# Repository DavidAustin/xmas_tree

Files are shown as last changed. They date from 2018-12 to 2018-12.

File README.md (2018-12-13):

# xmas_tree

An introduction-to-electronics project for kids around 10.

## Assembly

Assemble according to the schematic.

Soldering should be easy - except for the USB connector and perhaps the micro.

For the USB connector:
1. Put the connector in place, and hold it while flipping the PCB over.
2. Solder one of the ground pins that comes through the PCB to hold in place
3. Double check that it's in the right spot
4. Solder the remaining ground pins from the bottom.
5. Solder the signal pins using as little solder as you can.
6. If you bridge two pins, then you can use solder wick or remove with the soldering iron

To remove solder with the soldering iron, clean the tip with a wet sponge, apply the tip to the excess solder
and it will pick up a small amount.  Repeat cleaning and appplying tip to excess solder many times - say 10.

For the micro:
1. Ensure the right way around - there's a dot marking pin 1 - should go near the "U1" label.
2. Put in place and solder just one pin to hold it
3. Ensure in place, melt the soldered pin to adjust as necessary
4. Solder another pin on the far side
5. Ensure placement is still good.
6. Solder remaining pins
7. If you bridge two pins, then you can use solder wick or remove with the soldering iron

To remove solder with the soldering iron, clean the tip with a wet sponge, apply the tip to the excess solder
and it will pick up a small amount.  Repeat cleaning and appplying tip to excess solder many times - say 10.

For all the surface mount parts:
1. Apply solder to one pad
2. Position the part and melt the solder to join the part
3. Solder the remaining pad

For the LEDs (colour and front/back is at the user's discretion):
1. Short legs go near the flat side of the circle on the PCB outline - they all face the same direction
2. Put one leg in each hole and push down fairly close to the PCB.
3. Spread the legs slightly to hold in place
4. Solder both legs
5. Cut off excess with wire cutters

## Compiling

Under linux, avr-gcc is required.  Compile by typing

make

## Programming

sudo dfu-programmer atmega16u2 erase

sudo dfu-programmer atmega16u2 flash main.hex 

sudo dfu-programmer atmega16u2 start

To re-enter bootloader programming over USB, short (connect) between R21 and the nearby battery holder
and press the reset button.  A paperclip can be used.  When done right, LED21 will be on during the reset.

## Known Issues

Running from batteries will require programming the fuses - which can't be done over USB.  To be completed...

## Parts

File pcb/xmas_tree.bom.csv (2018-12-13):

Description | Device | Value | Footprint | Quantity | Supplier | Order Code | References
BATTERY HOLDER COIN 20MM SMD | BU2032SM-BT-GTR |  | CR2032_HOLDER | 2 | Digikey | BU2032SM-BT-GCT-ND | B1;B2
SWITCH TACTILE SPST-NO 0.05A 12V | SWITCH_PUSHBUTTON_NO |  | TACT6mm | 1 | Digikey | CKN9112CT-ND | BUT1
CAP CER 0.1UF 50V Y5V 0805 | CAPACITOR | 100nF | my0805 | 2 | Digikey | 1276-1007-1-ND | C1;C6
CAP CER 22PF 25V C0G/NP0 0805 | CAPACITOR | 22pF | my0805 | 2 | Digikey | 732-7829-1-ND | C2;C3
CAP CER 1UF 25V X7R 0805 | CAPACITOR | 1uF | my0805 | 1 | Digikey | 1276-1066-1-ND | C4
CONN RCPT USB2.0 MICRO B SMD R/A | 10118194-0001LF |  | usb_micro_b_10118194 | 1 | Digikey | 609-4618-1-ND | CONN1
LED RED CLEAR 5MM OVAL T/H | C5SMF-RJF-CT0W0BB2 |  | LED_5 | 7 | Digikey | C5SMF-RJF-CT0W0BB2CT-ND | LED10;LED11;LED12;LED13;LED14;LED8;LED9
LED GREEN CLEAR T-1 3/4 T/H | HLMP3950A |  | LED_5 | 7 | Digikey | 1080-1059-ND | LED15;LED16;LED17;LED18;LED19;LED20;LED21
5MM WHITE LED W/ WIDE VIEWING AN | BL-BZX3V4V-1-B02 |  | LED_5 | 7 | Digikey | BL-BZX3V4V-1-B02-ND | LED1;LED2;LED3;LED4;LED5;LED6;LED7
RES 120 OHM 5% 1/8W 0805 | RESISTOR | 120R | my0805 | 21 | Digikey | RMCF0805JT120RCT-ND | R1;R10;R11;R12;R13;R14;R15;R16;R17;R18;R19;R2;R20;R21;R3;R4;R5;R6;R7;R8;R9
CRGCQ 0805 22R 5% | RESISTOR | 22R | my0805 | 2 | Digikey | A130124CT-ND | R22;R23
RES 10K OHM 5% 1/8W 0805 | RESISTOR | 10k | my0805 | 1 | Digikey | RMCF0805JT10K0DKR-ND | R24
IC MCU 8BIT 16KB FLASH 32TQFP | ATMEGA16U2-AU |  | QFP32_70x70 | 1 | Digikey | ATMEGA16U2-AU-ND | U1
CRYSTAL 16.0000MHZ 18PF SMD | ABLS-16.000MHZ-B4-T |  | XTAL2_150x50 | 1 | Digikey | 535-10226-1-ND | X1
DNF PARTS:
Virtual part | HOLE |  | hole5 | 0 |  |  | H1
Virtual part | terminal |  | pad50x20 | 0 |  |  | T1
Virtual part | terminal |  | pad50x20 | 0 |  |  | T2
Virtual part | terminal |  | pad50x20 | 0 |  |  | T3
Virtual part | terminal |  | pad50x20 | 0 |  |  | T4
Virtual part | terminal |  | pad50x20 | 0 |  |  | T5
Virtual part | terminal |  | pad50x20 | 0 |  |  | T6
Virtual part | terminal |  | pad50x20 | 0 |  |  | T7
Virtual part | terminal |  | pad50x20 | 0 |  |  | T8

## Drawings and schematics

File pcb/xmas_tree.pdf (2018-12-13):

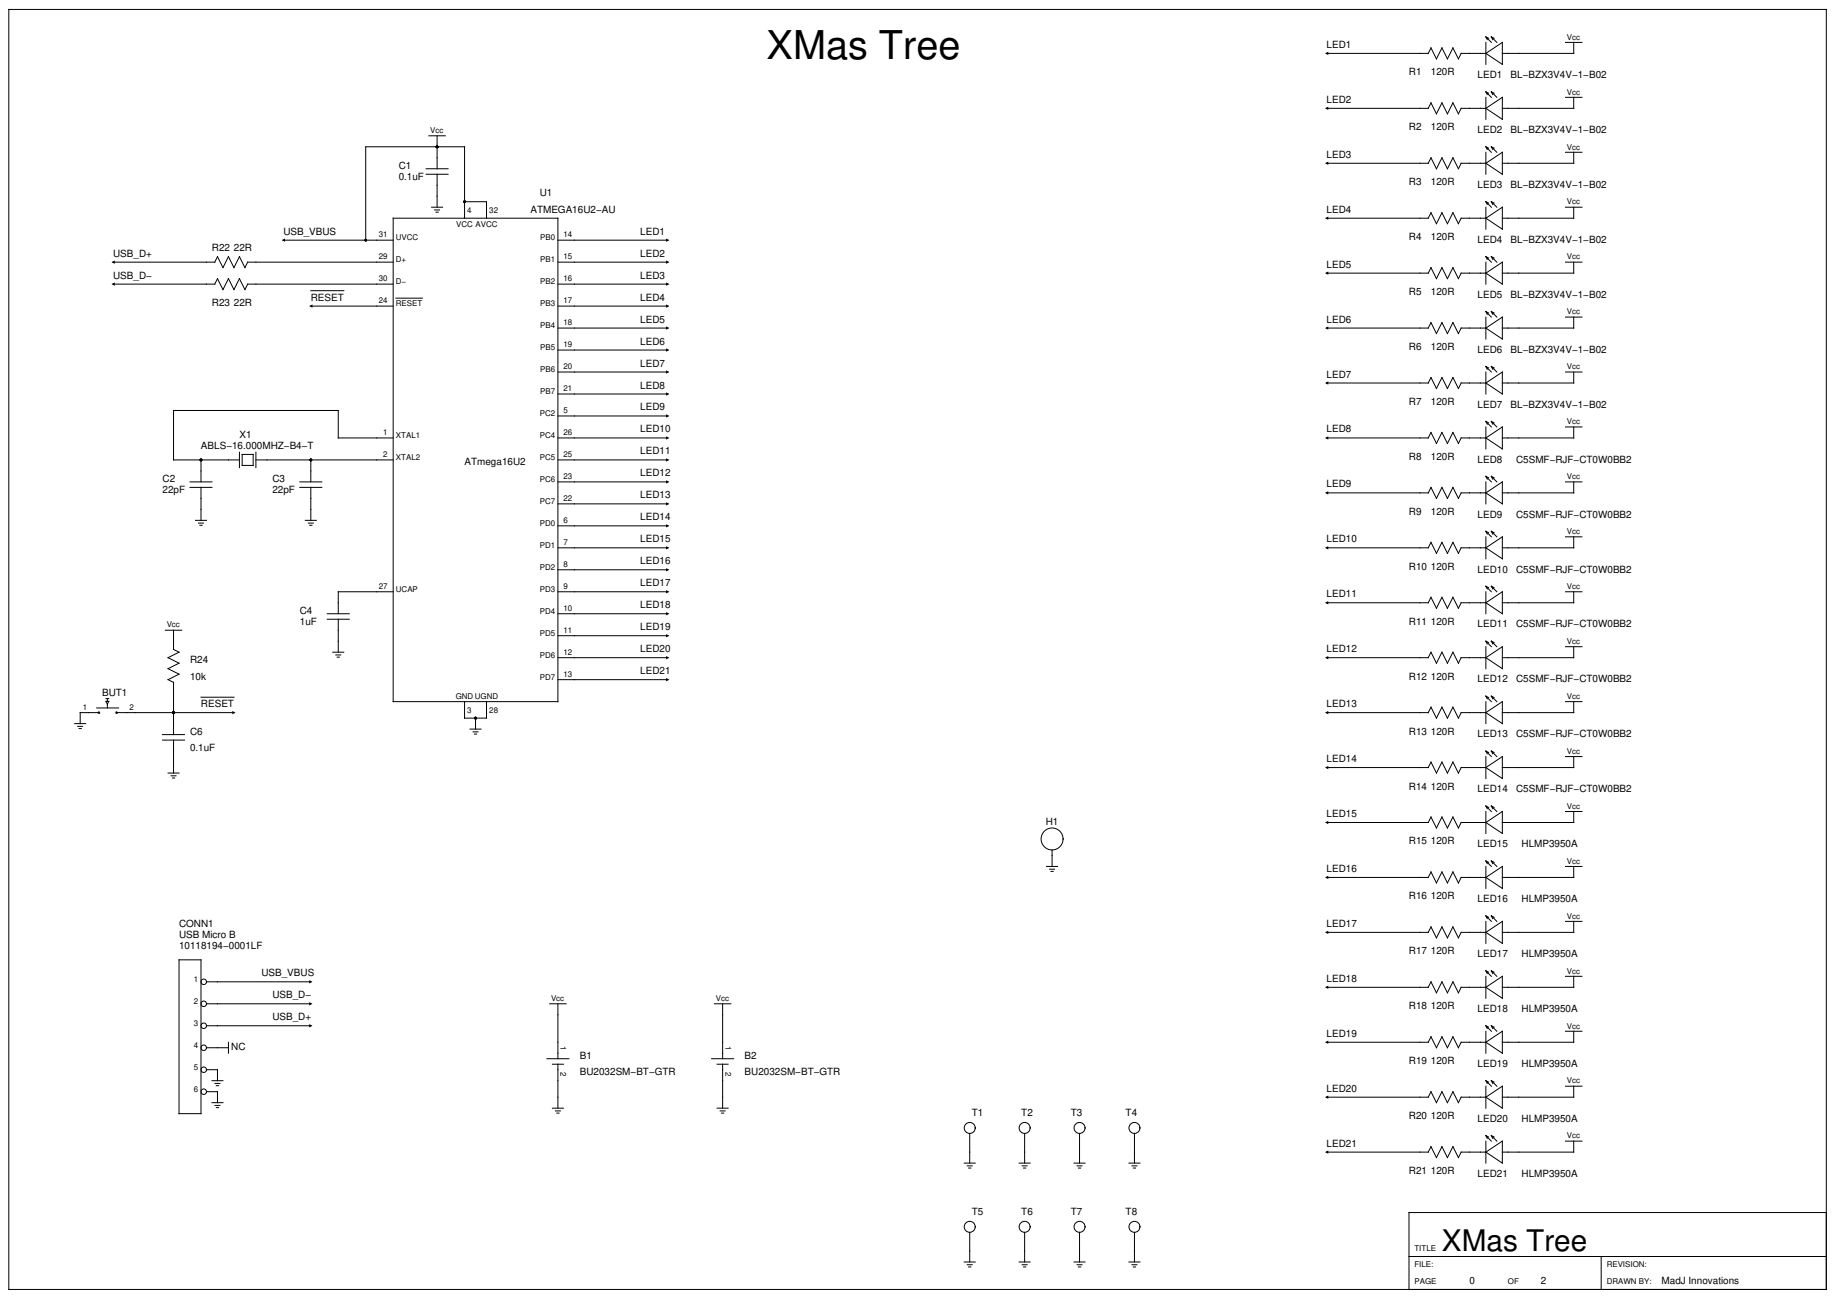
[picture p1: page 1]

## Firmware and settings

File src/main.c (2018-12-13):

#include <avr/io.h>
#include <avr/interrupt.h>
#include <avr/sleep.h>
 #define F_CPU 4000000UL
#include <util/delay.h>

typedef struct 
{
    uint8_t port;
    uint8_t pin;
} led_def_t;

#define PB   1
#define PC   2
#define PD   3
    
const led_def_t leds[] = 
{
    {.port=PB, .pin=0},
    {.port=PB, .pin=1},
    {.port=PB, .pin=2},
    {.port=PB, .pin=3},
    {.port=PB, .pin=4},
    {.port=PB, .pin=5},
    {.port=PB, .pin=6},
    {.port=PB, .pin=7},
    {.port=PC, .pin=2},
    {.port=PC, .pin=4},
    {.port=PC, .pin=5},
    {.port=PC, .pin=6},
    {.port=PC, .pin=7},
    {.port=PD, .pin=0},
    {.port=PD, .pin=1},
    {.port=PD, .pin=2},
    {.port=PD, .pin=3},
    {.port=PD, .pin=4},
    {.port=PD, .pin=5},
    {.port=PD, .pin=6},
    {.port=PD, .pin=7},
};

    
    
int main() 
{
    uint8_t idx;
    
    cli();
    
    //__disable_interrupt();
    //__watchdog_reset();
    /* Clear WDRF in MCUSR */
    MCUSR &= ~(1<<WDRF);
    /* Write logical one to WDCE and WDE */
    /* Keep old prescaler setting to prevent unintentional time-out */
    WDTCSR |= (1<<WDCE) | (1<<WDE);
    /* Turn off WDT */
    WDTCSR = 0x00;
    //__enable_interrupt();
    _delay_ms(1000);
    DDRB = 0xff;
    DDRC = _BV(2) | _BV(4) | _BV(5) | _BV(6) | _BV(7);
    DDRD = 0xff;

    idx = 0;
    
    while (1) {
	PORTB = 0xff;
	PORTC = 0xf4;
	PORTD = 0xff;

	if (leds[idx].port == PB) {
	    PORTB &= ~_BV(leds[idx].pin);
	} else if (leds[idx].port == PC) {
	    PORTC &= ~_BV(leds[idx].pin);
	} else if (leds[idx].port == PD) {
	    PORTD &= ~_BV(leds[idx].pin);
	}
	
	idx++;
	if (idx >= sizeof(leds)/sizeof(leds[0]))
	    idx = 0;
	
	
	_delay_ms(25);
    }

}
